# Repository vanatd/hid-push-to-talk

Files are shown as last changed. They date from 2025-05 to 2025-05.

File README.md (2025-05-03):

<h1 align="center">Push to talk (or mute😅)</h1>

If you, like me, love to multitask during long meetings in the meets and then are asked a question, you know how it is to find this hacking unmute button in thousands of open tabs!

I got fed up with it and built this HID project. This project is a very simple call-control HID. 

This device can help you mute/unmute yourself in the meets (maybe somewhere else, but I didn't test it) from anywhere. Also, this small device reduces the mental load of finding the mic button with a mouse.

This project has almost all you need: CAD if you want to adjust the project to yourself, STLs/3MFs to print, and source code build for the Arduino Pro Micro.

This project was based on several open-source projects. However, I updated/redesigned 80% of these projects.

---

## Feature

* Call control:
    * Mute
    * Unmute
    * Swap state (ie push-to-talk, push-to-mute)
* Led to show the state
    * Led is on - unmuted
    * Led is off - muted

---

## Preview

<p align="center">
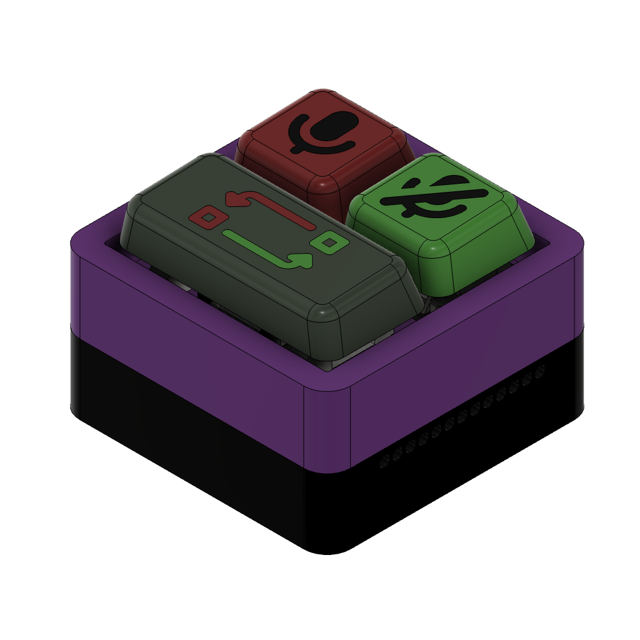
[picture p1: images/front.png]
  
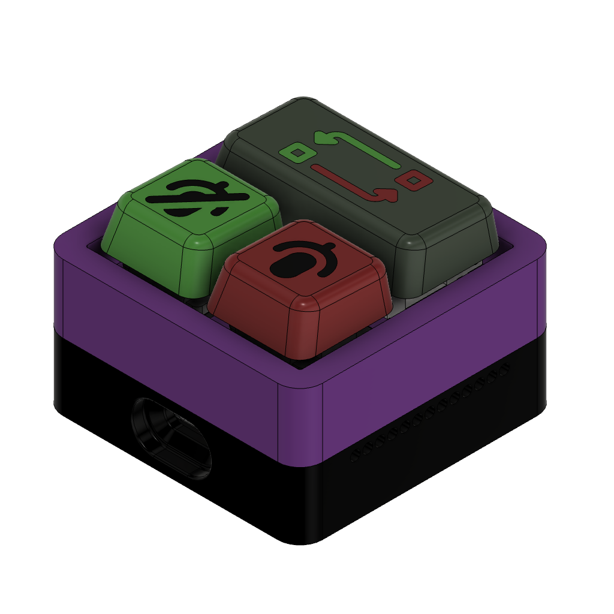
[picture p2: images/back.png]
  
</p>

Here, you can see the render. I've played a bit with the design to make it juicy 😁

The project has holes on the sides to put transparent filament so you can see what mode the device is in now, muted or unmuted.

<p align="center">
  
  
</p>

As you can see, after connecting this call-control HID to Google Meet, you can mute/unmute the call from any place/program when the tab is inactive, even when Chrome is inactive.

---

## What to Print

- Box top 
- Box bottom
- Arduino Pro Micro holder
- Keycaps
    - 1u x2
    - 2u
- Stibilizer x2

---

## What to Buy

Name                    | amount|
--------                |-------|
Arduino Pro Micro       | 1
Key switch              | 3
Khail hotswap           | 3
M3x3x4.2 Bras inserts   | 4
M3 bolt                 | 4  
M3 nuts                 | 2
M3 bolt hidden head     | 2
Steel wire              | ~50mm

---

## Wiring schematic

<p align="center">
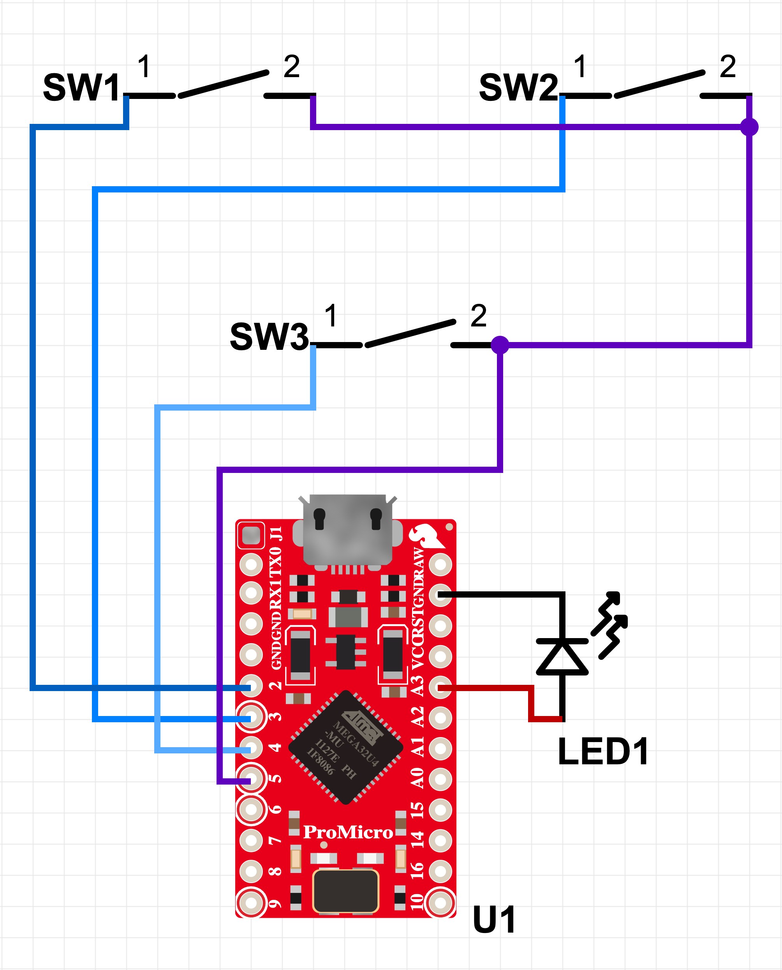
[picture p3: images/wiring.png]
  
</p>

---

## How to use

Here is a great document from Google Meet on [how to add a call control device](https://support.google.com/meet/answer/12562325).

---

## Known issues

* The HID device implemented simple call control, and it has no synchronization. So, if you mute/unmute yourself from the Google Meets tab, the device will state in the previous mode. *Or I not found it*

* Sometimes, the swap button gets released while you are still holding it.

---

## ☕ Buy Me a Coffee

If you found this project helpful, I would appreciate your support!

You can buy me a coffee, which I love, by the way 😅

<p align="center">
  <a href="https://ko-fi.com/R5R81E1SZM" target="_blank">
    
  </a>
</p>

Or you can donate to any of the Ukrainian volunteer foundations!

Слава Україні! Героям Слава!

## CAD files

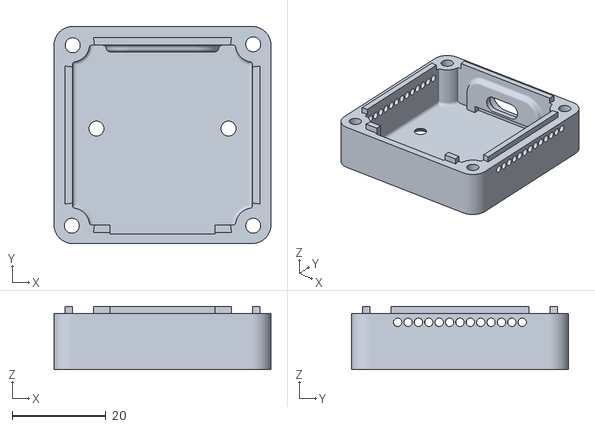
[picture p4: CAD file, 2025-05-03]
stls/Box bottom.stl
46.4 x 46.4 x 13.5

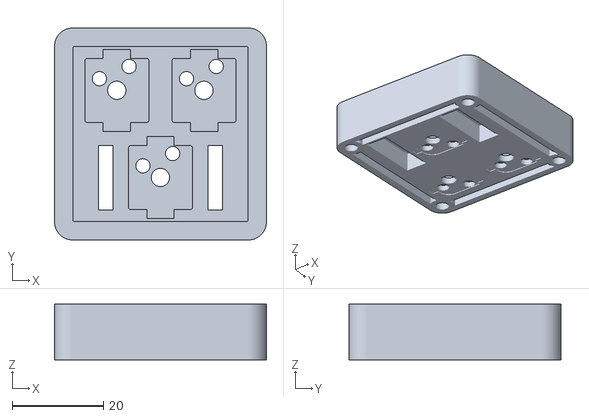
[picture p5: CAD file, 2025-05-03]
stls/Box top.stl
46.4 x 46.4 x 12.2

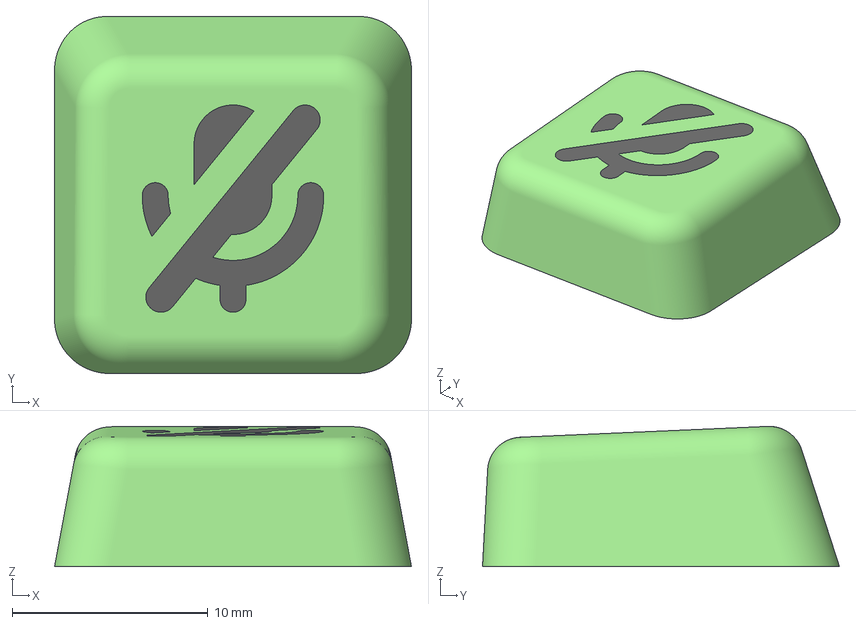
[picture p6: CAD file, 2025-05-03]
stls/Mute btn.3mf
18.2 x 18.2 x 7.16 mm

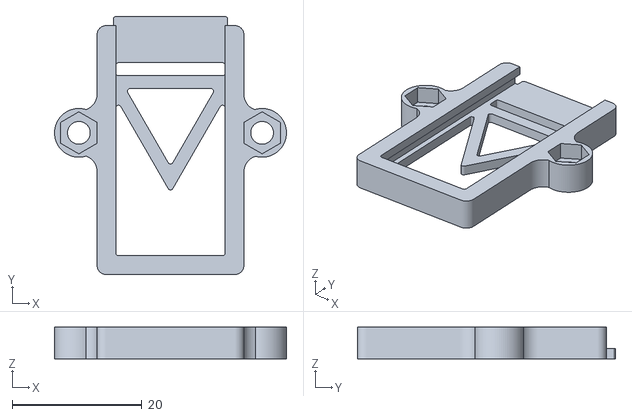
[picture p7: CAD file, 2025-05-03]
stls/ProMicroHolder.stl
35.7 x 39.7 x 4.86

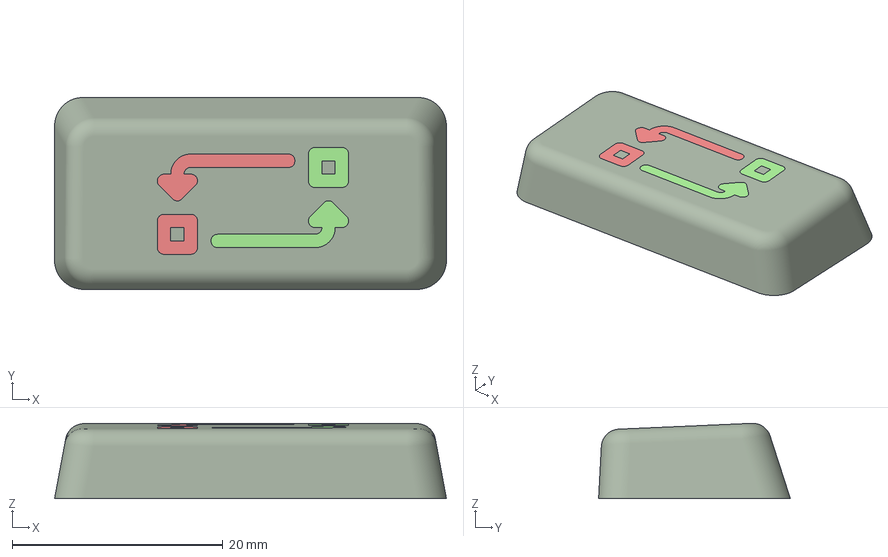
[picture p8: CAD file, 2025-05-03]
stls/Swap btn.3mf
37.2 x 18.2 x 7.16 mm

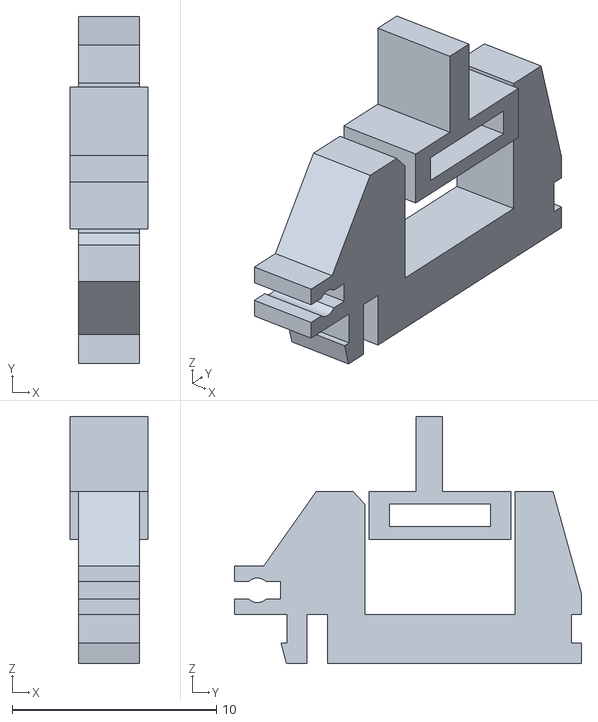
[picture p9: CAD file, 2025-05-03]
stls/stabilizer.stl
3.81 x 17.0 x 12.1

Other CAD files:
stls/Unmute btn.3mf
stls/Mute btn.stl
stls/Swap btn.stl
stls/Unmute btn.stl

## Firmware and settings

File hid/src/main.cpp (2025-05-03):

#include <Arduino.h>
#include <Keypad.h>
#include <HID-Project.h>

#include <Led.cpp>
#include <State.cpp>
#include <StateManager.cpp>
#include <MutedState.cpp>
#include <UnmutedState.cpp>

int C1 = 2;
int C2 = 3;
int C3 = 4;
int R1 = 5;

const byte ROWS = 1;
const byte COLS = 3;

char keys[ROWS][COLS] = { {'s', 'u', 'm'} };
byte rowPins[ROWS] = {R1};
byte colPins[COLS] = {C3, C2, C1};

Keypad kpd = Keypad(makeKeymap(keys), rowPins, colPins, ROWS, COLS);

StateManager stateMng = StateManager(&Phone);

Led led = Led(A3);

MutedState muted = MutedState(&led);
UnmutedState unmuted = UnmutedState(&led);

void listener(char key) {
  if(key == 's') {
    if(kpd.isPressed(key)) {
      stateMng.pressed();
    } else {
      stateMng.released();
    }
  }
};

void setup(){
  Serial.begin(9600);
  Phone.begin();
  
  led.begin();

  stateMng.setState(&muted);
  
  kpd.setHoldTime(1000 * 60 * 60);

  kpd.addEventListener(listener);
}

void loop(){
  char key = kpd.getKey();

  if (key) {
    if(key == 'm'){ 
      stateMng.setState(&muted);
    }

    if(key == 'u'){ 
      stateMng.setState(&unmuted);
    }
  }
}
